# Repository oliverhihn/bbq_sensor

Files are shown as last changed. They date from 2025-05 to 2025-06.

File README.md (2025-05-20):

# BBQ Temperature Sensor Project

This project is a BBQ temperature sensor that allows you to monitor the temperature of your BBQ grill or smoker remotely. It uses a Thermocouple with a MAX31855 amplifier temperature sensor to measure the temperature and an ESP8266 (D1 Mini) microcontroller to send the data to a web server. The project is designed to be easy to set up and use.

## PCB Setup

For a more stable and compact design, a custom PCB was created. The PCB is designed to hold the D1 Mini microcontroller and the MAX31855 amplifier.

image:
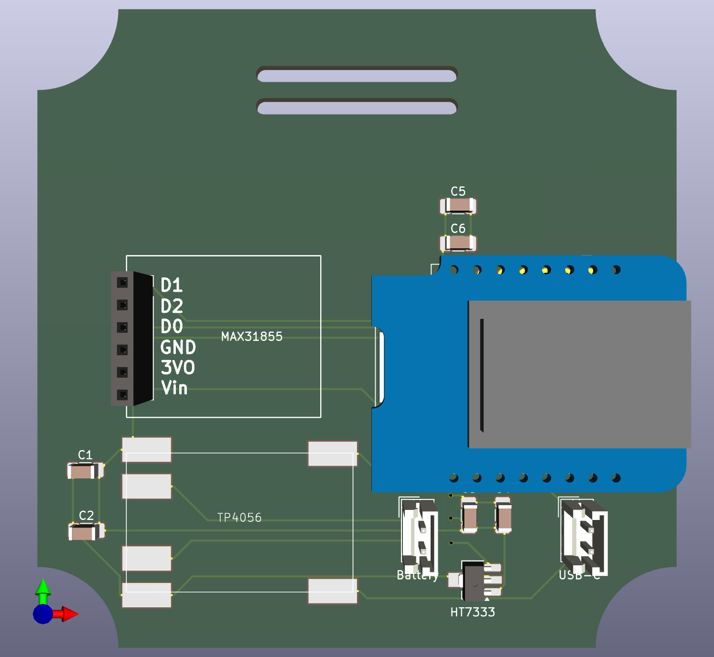
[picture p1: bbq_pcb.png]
PCB


## ESPHome Setup

The project uses ESPHome to manage the D1 Mini microcontroller. ESPHome is a system that allows you to control your ESP8266/ESP32 devices through simple yet powerful configuration files and control them remotely through Home Assistant.

```yml
esp8266:
  board: d1_mini

spi:
  miso_pin: D0
  clk_pin: D1

sensor:
  - platform: max31855
    name: "BBQ Temperature"
    cs_pin: D2
    update_interval: 10s
```

## Parametric Box

Thank you to [@pbtec_14016](https://www.printables.com/@pbtec_14016) for the original design of the box. The original design was modified to fit the PCB and the D1 Mini microcontroller. The box is designed to be 3D printed and has cutouts for the thermocouple and the D1 Mini microcontroller.

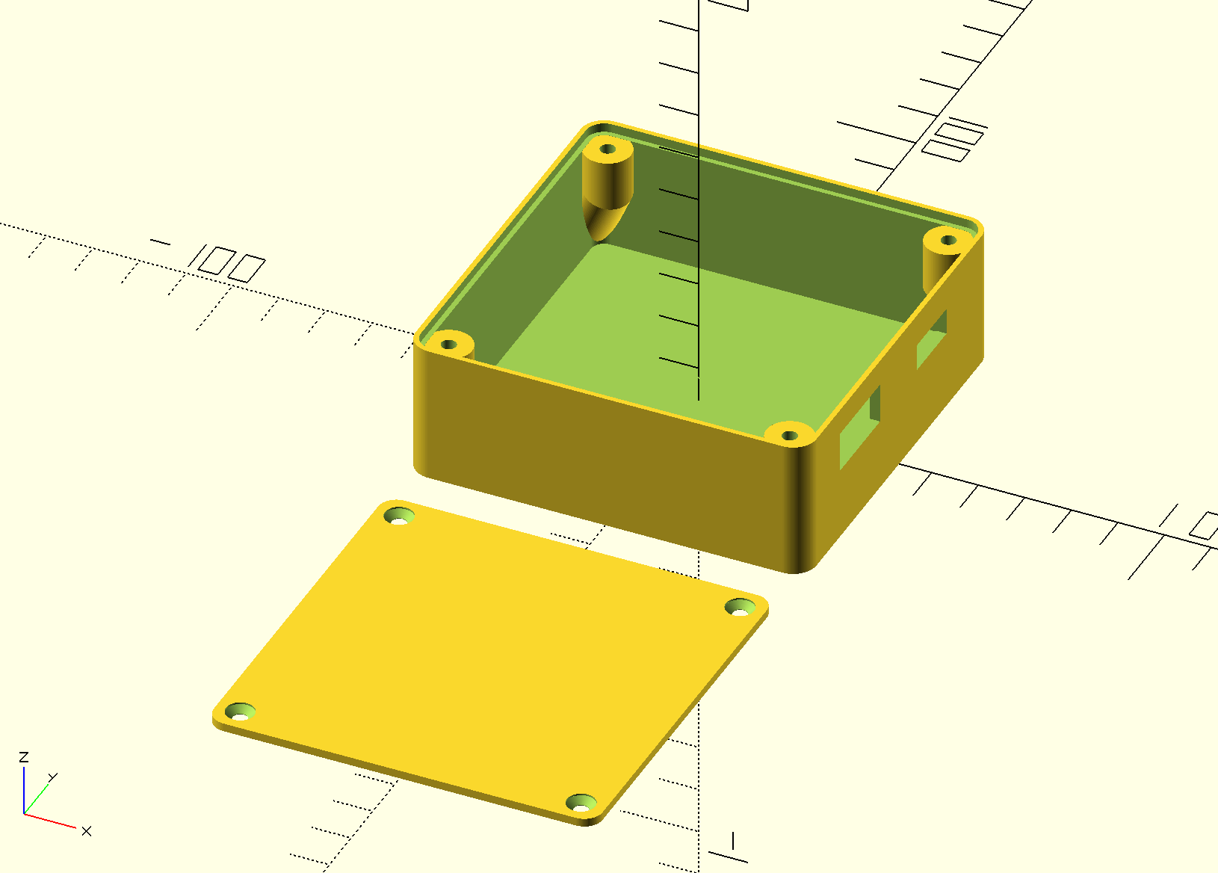
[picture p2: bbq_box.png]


Only things changed from the original design are the Holes in the wall of the box for the cables, the count of screws for the lid, and the dimensions.
The box is designed to be printed in one piece, with no need for supports. The design is parametric, allowing you to easily adjust the dimensions to fit your needs.

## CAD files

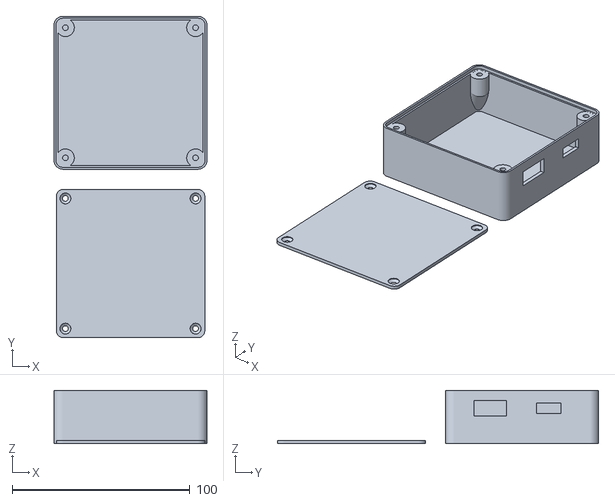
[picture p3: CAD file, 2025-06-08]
bbq_box.stl
86.0 x 180.7 x 30.0

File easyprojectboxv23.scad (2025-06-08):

/*******************************************************************************
TITLE:
Easy box for electronic projects by pbtec

LICENSE:
Licensed under the Creative Commons - Attribution - Non-Commercial - Share Alike

DESCRIPTION:
Use Openscad customizer (Menu Window/unselect "hide customizer") to customize this box
I am aware that sometimes, when using too big or too small parameters, there are some rendering issues.
To prevent such issues, change only one parameter at once and check the result.

Customize:
- Use the first 4 modules to add objects or to cut out holes (there are already a few examples, uncomment them to use)
- Export the stl file from Openscad (F6 then F7). Then Import the stl file into your best known 3d program to make holes.
- You can also make the holes afterwards with the drilling machine.

Hope you can use it for you projects
Let me see your prints, and remakes and pls do not forget to press the like button

use https://paypal.me/pbtec if you want to spend me a coold beer. Thanks in advance :-)

AUTHOR:
pbtec / pb-tec.ch

VERSION:
V   KZZ DATE     COMMENT
1.0 pb  31.08.22 First Version to share
2.0 pb  08.07.23 Optimized Version with more customizations
2.1 pb  11.12.23 Some updates
2.2 pb  27.04.24 Final Version to share
2.3 pb  10.06.24 Size more granular possible
*******************************************************************************/

/* [View settings] */
// Quality variable (40 fast / 150 for creating printable stl files)
$fn                       =            100 ; // [10:1:400]
// Quality variable interior parts (due to performance matter I would not go over 50)
$fnInterior               =            100 ; // [10:1:200]
Show                      =              0 ; // [0:Body and lid, 1:Body only, 2:lid only]
// Distance between Body and lid 10mm or more
Dist                      =             10 ;
// unselected=Body centered, selected=lid centered
Position                  =          false ;
/* [Box settings] */
// Size for the box x,y,z
Size                      =   [86,86,30] ;
// Corner rounding --> !!! Rounding must be same or bigger than WallThick, and not bigger than the half of the smaler side -1. Otherwise there are some rendering issues
Rounding                  =            5.0 ; //[1:1:100]
// Wall and bottom thickness
WallThick                 =            2.2 ; //[1:0.1:10]
// Lid thickness (only lid)
LidThick                  =            1.8 ; //[1:0.1:10]
// Gap between base and lid to make the lid a bit smaler to fit better (depends on your 3d printer quality) default 0.2mm
Gap                       =            0.2 ; //[0.01:0.01:1]
// Hole diameter in lid for Screw
/* [Screw / hot melt copper nut settings] */
// Size for the hole in the lid
HoleDiaLid                =            3.2 ; //[1:0.1:10]
// Hole diameter for thread or hot melt copper nut (thread 2.2 for 2.9mm / 2.8 for 3.5mm / 3.2 for 3.9mm Screw)
HoleDiaThread             =            3.2 ; //[1:0.1:10]
// Screw or hot melt nut Hole deepness (deepness in the Body/Cylinder). If too big, through hole possible
HoleDeepness              =           10.0 ; //[1:0.1:200]
// Cylinder dia for the Screw
ScrewCylinderDia          =           10.0 ; //[4:0.1:20]
// Add additional holes on x side
AddXScrew                 =           false ;
// Add additional holes on y side
AddYScrew                 =           false ;
// For stability you can connect the cylinder to the wall
ConnectCylinder           =           true ;
// Add chamfer to the bottom of the cylinder (depends on the HoleDeepness parameter). Use only when the cylinder is connected with the wall or when ConnectCylinder is activated
AddChamfer                =           true ;
//  Chamfer cut angle. Default 22. I would not go bigger than 45 to prevent printing issues, besides you use support
ChamferAngle              =             35 ;
// Select the using screw head
HoleType                  =              1 ; // [0:Hole only, 1:Countersink, 2:Normal screw head]
// CounterSink screw head diameter (use measured value) --> 5.5 for M3
CSHeadDia                 =            5.5 ; //[1:0.1:20]
// NormalScrew: Head diameter, screw head high (The hole will be the size you enter)
NSHeadSize                =        [6,2.5] ; //[1:0.1:20]
// Side hole distance from the outside of the body. Check the holes position on the lid
HolePos                   =            7.0 ; //[3:0.1:20]


/* [PCB body mounting cylinders 1] */
// Activate PCB mount cylinders on body
PCB_BodyMountCylActive    =          false ;
// Cylinder high
PCB_BodyCylHigh           =           14.0 ;  //[1:0.1:30]
// Cylinder diameter
PCB_BodyCylDia            =           12.0 ;  //[1:1:20]
// Cylinder thread hole (for screws or hot melt copper nut)
PCB_BodyCylHoleDia        =            3.8 ; //[1:0.1:15]

// X distance beteween the holes
PCB_BodyX_Dist            =           30.0 ;  //[1:0.1:1000]
// Y distance beteween the holes
PCB_BodyY_Dist            =           50.0 ;  //[1:0.1:1000]
// PCB X direction offset (+/-)
PCB_BodyX_offset          =          -30.0 ;  //[-1000:0.1:1000]
// PCB Y direction offset (+/-)
PCB_BodyY_offset          =            0.0 ;  //[-1000:0.1:1000]

/* [PCB body mounting cylinders 2] */
// Activate PCB mount cylinders on body
PCB_Body2MountCylActive   =          false ;
// Cylinder high
PCB_Body2CylHigh          =            8.0 ;  //[1:0.1:30]
// Cylinder diameter
PCB_Body2CylDia           =            8.0 ;  //[1:1:20]
// Cylinder thread hole (for screws or hot melt copper nut)
PCB_Body2CylHoleDia       =            3.8 ; //[1:0.1:15]

// X distance beteween the holes
PCB_Body2X_Dist           =           25.0 ; //[1:0.1:1000]
// Y distance beteween the holes
PCB_Body2Y_Dist           =           30.0 ; //[1:0.1:1000]
// PCB X direction offset (+/-)
PCB_Body2X_offset         =           30.0 ; //[-1000:0.1:1000]
// PCB Y direction offset (+/-)
PCB_Body2Y_offset         =           18.0 ; //[-1000:0.1:1000]

/* [PCB Lid mounting cylinders 1. Turn object upside down to see it ;-)] */
// Activate PCB mount cylinders on Lid
PCB_LidMountCylActive     =          false ;
// Cylinder high
PCB_LidCylHigh            =            8.0 ;  //[1:0.1:30]
// Cylinder diameter
PCB_LidCylDia             =            7.0 ;  //[1:1:20]
// Cylinder thread hole (for screws or hot melt copper nut)
PCB_LidCylHoleDia         =            3.8 ; //[1:0.1:15]

// X distance beteween the holes
PCB_LidX_Dist             =           30.0 ; //[1:0.1:1000]
// Y distance beteween the holes
PCB_LidY_Dist             =           50.0 ; //[1:0.1:1000]
// PCB X direction offset (+/-)
PCB_LidX_offset           =           30.0 ; //[-1000:0.1:1000]
// PCB Y direction offset (+/-)
PCB_LidY_offset           =            0.0 ; //[-1000:0.1:1000]

/* [PCB Lid mounting cylinders 2. Turn object upside down to see it ;-)] */
// Activate PCB mount cylinders on Lid
PCB_Lid2MountCylActive     =         false ;
// Cylinder high
PCB_Lid2CylHigh            =          12.0 ;  //[1:0.1:30]
// Cylinder diameter
PCB_Lid2CylDia             =          10.0 ;  //[1:1:20]
// Cylinder thread hole (for screws or hot melt copper nut)
PCB_Lid2CylHoleDia         =           4.6 ; //[1:0.1:15]

// X distance beteween the holes
PCB_Lid2X_Dist             =          40.0 ; //[1:0.1:1000]
// Y distance beteween the holes
PCB_Lid2Y_Dist             =          30.0 ; //[1:0.1:1000]
// PCB X direction offset (+/-)
PCB_Lid2X_offset           =         -30.0 ; //[-1000:0.1:1000]
// PCB Y direction offset (+/-)
PCB_Lid2Y_offset           =          20.0 ; //[-1000:0.1:1000]

/* [Control cuts] */
HorizontalCut             =          false ;
VerticalCut               =          false ;
DiagonalCut               =          false ;

/* [Project] */
Buy_PBTEC_a_Beer          =          false ;
// M A I N
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

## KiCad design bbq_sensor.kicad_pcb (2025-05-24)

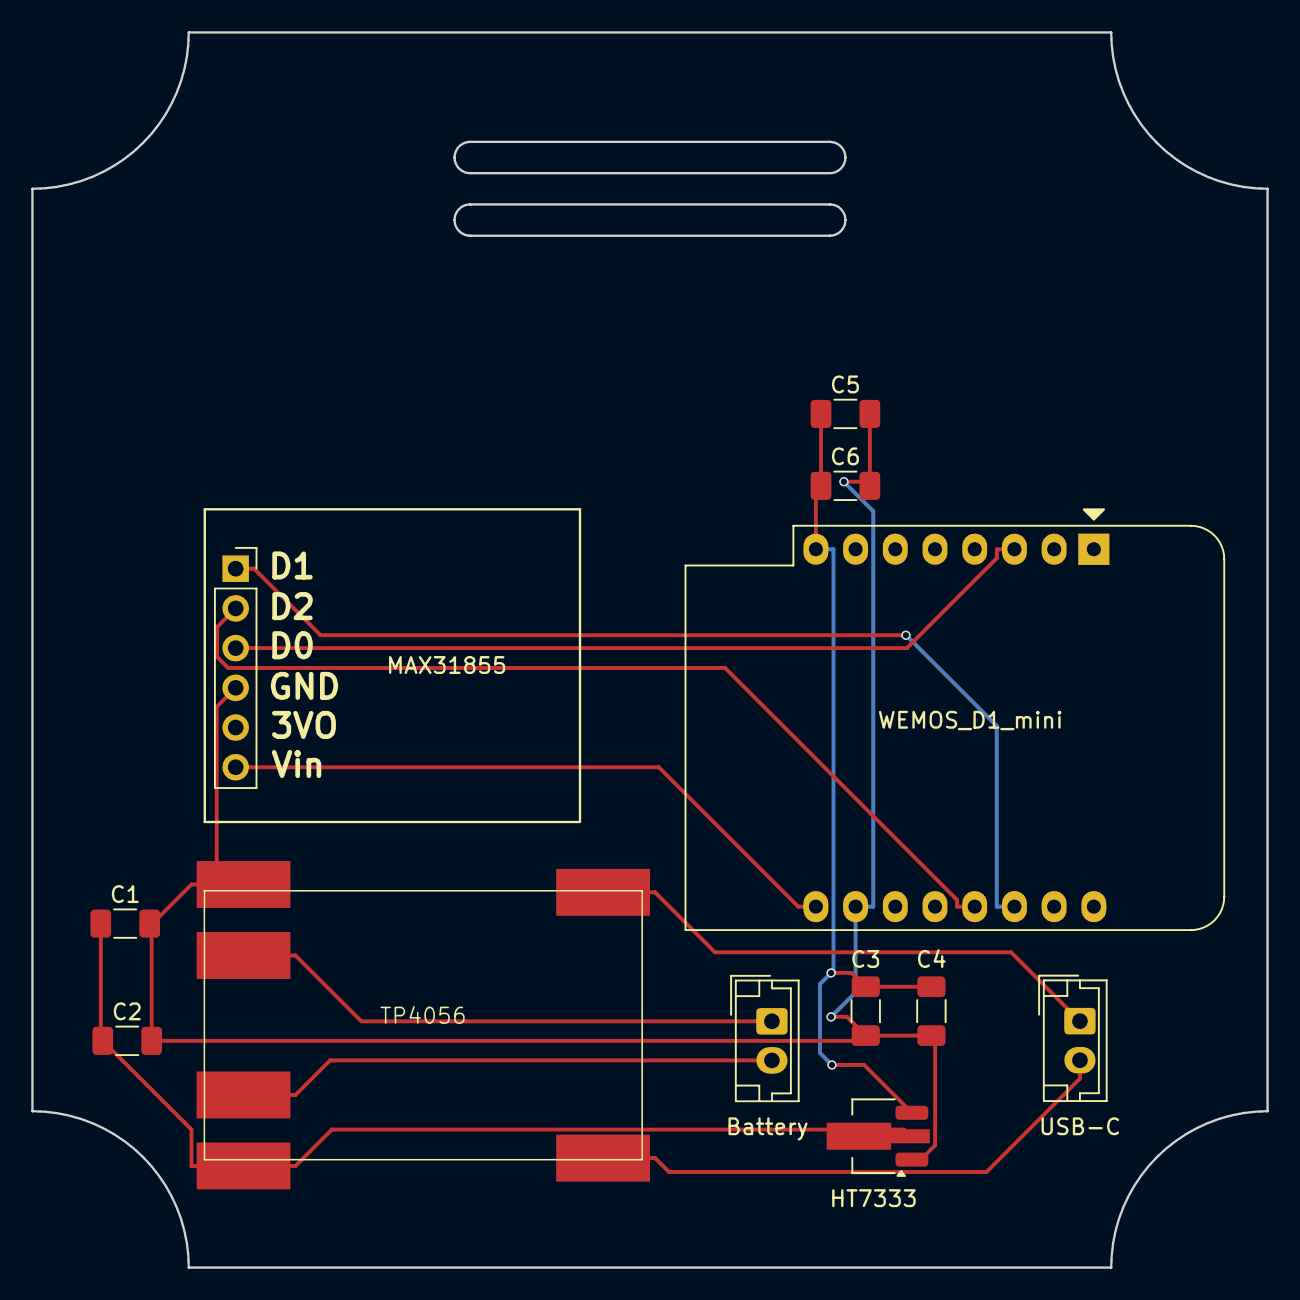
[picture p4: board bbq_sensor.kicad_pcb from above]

Board: 2 copper layers, 79.0 x 79.0 mm, 12 parts (0 on the bottom side), 11 nets.

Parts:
Battery: Battery_Conn; JST_EH_B2B-EH-A_1x02_P2.50mm_Vertical
C1, C5: 47 µF MLCC; C_1206_3216Metric_Pad1.33x1.80mm_HandSolder
C2: 100 µF Elco; C_1206_3216Metric_Pad1.33x1.80mm_HandSolder
C3: 10 µF MLCC; C_1206_3216Metric_Pad1.33x1.80mm_HandSolder
C4, C6: 0.1 µF MLCC; C_1206_3216Metric_Pad1.33x1.80mm_HandSolder
HT7333: HT7333; SOT-89-3_Handsoldering
MAX31855: Conn_01x06_Socket; PinSocket_1x06_P2.54mm_Vertical
TP4056: tp4056-module
U2: WEMOS_D1_mini; WEMOS_D1_mini_light
USB-C: USB-C_Conn; JST_EH_B2B-EH-A_1x02_P2.50mm_Vertical

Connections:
unnamed: Battery.2 (Battery_+), TP4056.5 (B+)
unnamed: Battery.1 (Battery_-), TP4056.6 (B-)
unnamed: TP4056.1 (Vin+), USB-C.2 (Vin+)
unnamed: TP4056.2 (Vin-), USB-C.1 (Vin-)
unnamed: MAX31855.3 (D0_DO), U2.3 (D0)
unnamed: MAX31855.1 (D1_CLK), U2.14 (SCL/D1)
unnamed: MAX31855.2 (D2_CS), U2.13 (SDA/D2)
unnamed: C1.2, C2.2, C3.2, C4.2, C5.2, C6.2, HT7333.1 (VIN), MAX31855.4 (GND), TP4056.4 (Vout-), U2.10 (GND)
unnamed: MAX31855.6 (VIN), U2.9 (5V)
unnamed: C1.1, C2.1, HT7333.2 (GND), TP4056.3 (Vout+)
unnamed: C3.1, C4.1, C5.1, C6.1, HT7333.3 (VOUT), U2.8 (3V3)

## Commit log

2025-05-20 added box
    [bbq_box.stl, easyprojectboxv23.scad]
2025-05-20 fix holesize
    [bbq_box.stl, easyprojectboxv23.scad]
2025-05-21 usb-c port instead of hole
    [bbq_box.stl, easyprojectboxv23.scad]
2025-05-21 fix conflict
    [easyprojectboxv23.scad]
2025-05-21 decreased box height
    [bbq_box.stl, easyprojectboxv23.scad]
2025-05-21 improved pcb
    [bbq_sensor.kicad_pcb, bbq_sensor.kicad_sch]
2025-05-21 update image of pcb
2025-05-22 update board
    [bbq_sensor.kicad_pcb, bbq_sensor.kicad_sch]
2025-05-23 added caps
    [bbq_sensor.kicad_pcb, bbq_sensor.kicad_sch]
2025-05-24 update image
    [bbq_sensor.kicad_pcb]
2025-06-08 update box and images
    [bbq_box.stl, easyprojectboxv23.scad]
